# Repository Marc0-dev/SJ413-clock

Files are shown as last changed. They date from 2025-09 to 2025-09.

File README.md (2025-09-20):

# SJ413-clock
**DISCLAMER** 
The PCB dimensions are approximate, the position of the screw holes is not correct, feel free to contribute in this regard.<br />
You must have the original plastic casing to assemble the clock.<br />
Pointers are much appreciated(i'm still an amateur in electronics).<br />
This project is not complete(it may change and improve in the future).
immagine
immagine

The project is a replacement of the original suzuki sj-413 dashboard clock. All code on these repository is made using platformIO, leveraging the inexpensive wch ch32v003f4p6 MCU.<br />
List of components(lcsc part numbers):<br />
C1(100nf): C14663, <br />
C2(1uf): C28322, <br />
C3(470uf):C5162352, <br />
C4(330uf):C3032175, <br />
C5(12pf):C76948, <br />
C6(100nf):C14663, <br />
D1:C5357977, <br />
D2:C552776, <br />
J1(oled display connector), <br />
J2(wch-linke interface), <br />
J4(molex connector for rtc), <br />
J5(power connector), <br />
L1(47uh/2A): C5189938, <br />
R1(4k7):C99782, <br />
R2(4k7):C99782, <br />
U1(mcu):C5187096, <br />
U2(buck converter):C2681226, <br />
U3(real time clock):C7440, <br />
Y1:C90945, <br />
display used: C5248081, <br />
# external connection
connector
you should use only the top row of the connector: the left one is positive, the right one is negative
#Images(from previous iteration, without reverse current protection):
immagine
immagine

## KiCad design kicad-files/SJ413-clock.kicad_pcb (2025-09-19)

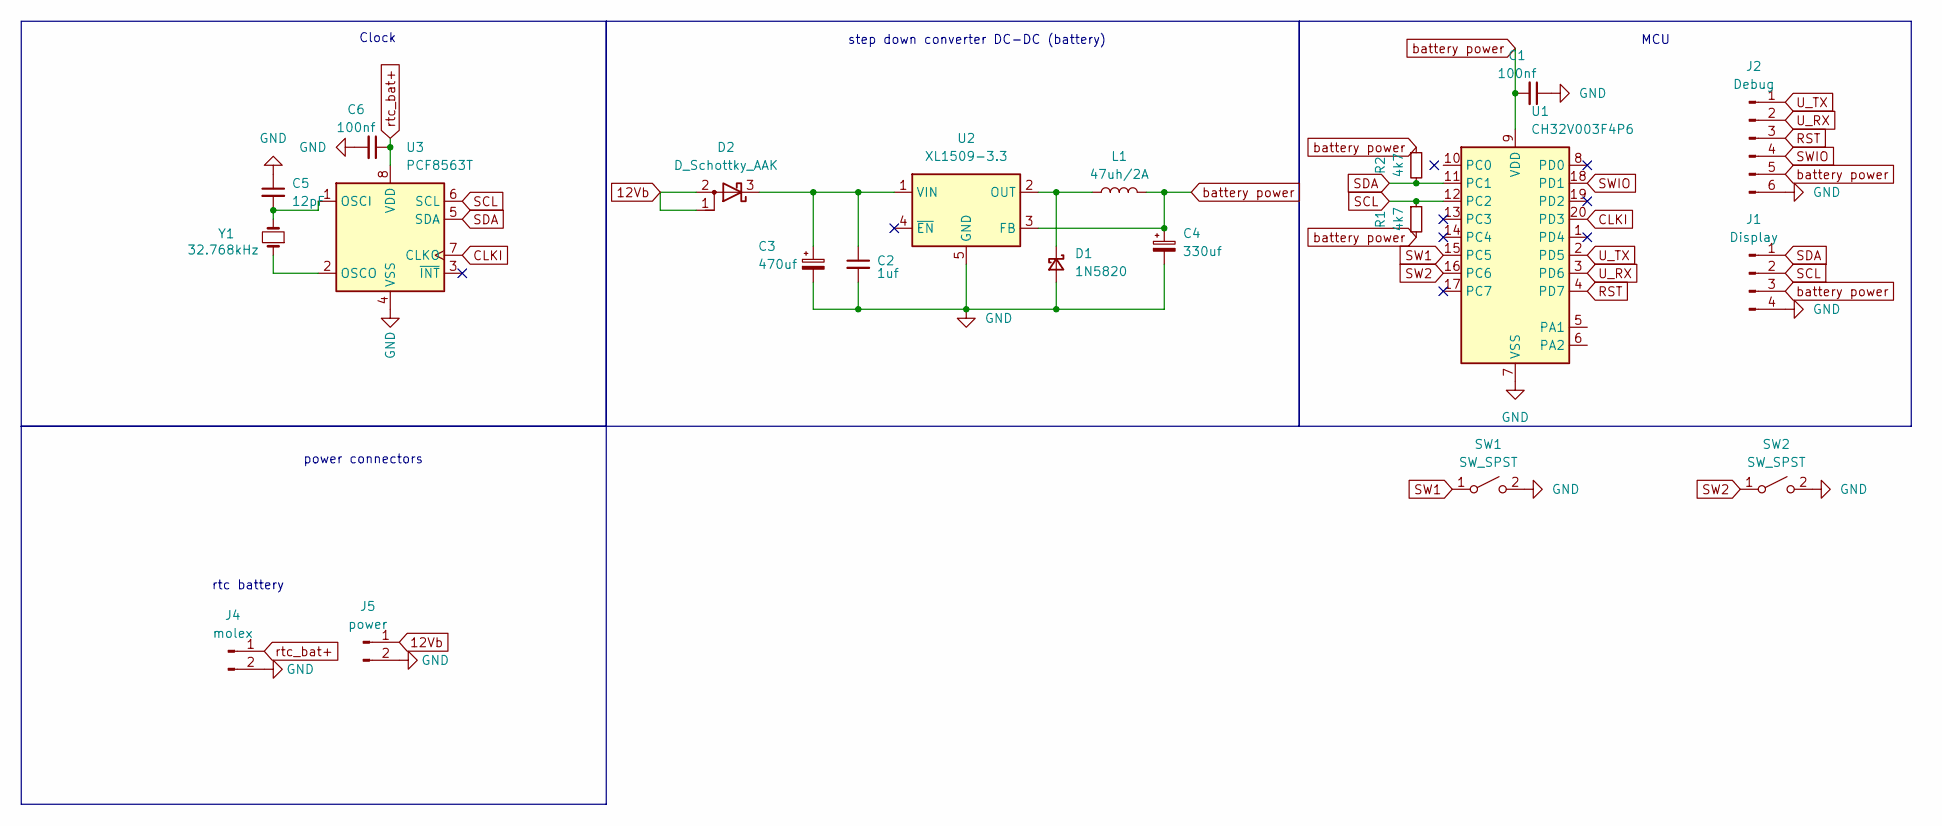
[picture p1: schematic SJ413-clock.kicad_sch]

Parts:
C1, C6: 100nf; C_0603_1608Metric; MPN CC0603KRX7R9BB104
C2: 1uf; C_1206_3216Metric
C3: 470uf; CP_Elec_10x10.5
C4: 330uf; CP_Elec_10x10.5
C5: 12pF; C_0402_1005Metric; MPN 0402CG120J500NT
D1: 1N5820; D_DO-201AD_P15.24mm_Horizontal
D2: D_Schottky_AAK; DIO_PMEG050V150EPDZ
J1: Display; PinHeader_1x04_P2.54mm_Vertical_SMD_Pin1Left
J2: Debug; PinSocket_1x06_P2.54mm_Vertical_SMD_Pin1Left
J4: molex; Molex_PicoBlade_53047-0210_1x02_P1.25mm_Vertical
J5: power; PinSocket_1x02_P2.54mm_Vertical_SMD_Pin1Left
L1: 47uh/2A; L_Sumida_CDMC6D28_7.25x6.5mm
R1, R2: 4k7; R_0603_1608Metric
SW1, SW2: SW_SPST; membrane switch
U1: CH32V003F4P6; TSSOP-20_4.4x6.5mm_P0.65mm; MPN CH32V003F4P6
U2: XL1509-3.3; SOIC-8_3.9x4.9mm_P1.27mm
U3: PCF8563T; SOIC-8_3.9x4.9mm_P1.27mm; MPN PCF8563T/5,518
Y1: 32.768kHz; Crystal_SMD_3215-2Pin_3.2x1.5mm; MPN 9H03200034

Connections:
12Vb: D2.1 (A), D2.2 (A), J5.1
CLKI: U1.20 (PD3), U3.7 (CLKO)
GND: C1.1, C2.2, C3.2, C4.2, C5.1, C6.2, D1.2 (A), J1.4, J2.6, J4.2, J5.2, SW1.2 (B), SW2.2 (B), U1.7 (VSS), U2.5 (GND), U2.6 (GND), U2.7 (GND), U2.8 (GND), U3.4 (VSS)
unnamed: D1.1 (K), L1.1, U2.2 (OUT)
unnamed: C2.1, C3.1, D2.3 (K), U2.1 (VIN)
unnamed: C5.2, U3.1 (OSCI), Y1.2
unnamed: U3.2 (OSCO), Y1.1
RST: J2.3, U1.4 (PD7)
SCL: J1.2, R1.1, U1.12 (PC2), U3.6 (SCL)
SDA: J1.1, R2.2, U1.11 (PC1), U3.5 (SDA)
SW1: SW1.1 (A), U1.15 (PC5)
SW2: SW2.1 (A), U1.16 (PC6)
SWIO: J2.4, U1.18 (PD1)
U_RX: J2.2, U1.3 (PD6)
U_TX: J2.1, U1.2 (PD5)
battery power: C1.2, C4.1, J1.3, J2.5, L1.2, R1.2, R2.1, U1.9 (VDD), U2.3 (FB)
rtc_bat+: C6.1, J4.1, U3.8 (VDD)

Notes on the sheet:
MCU
power connectors
Clock
step down converter DC-DC (battery)
rtc battery

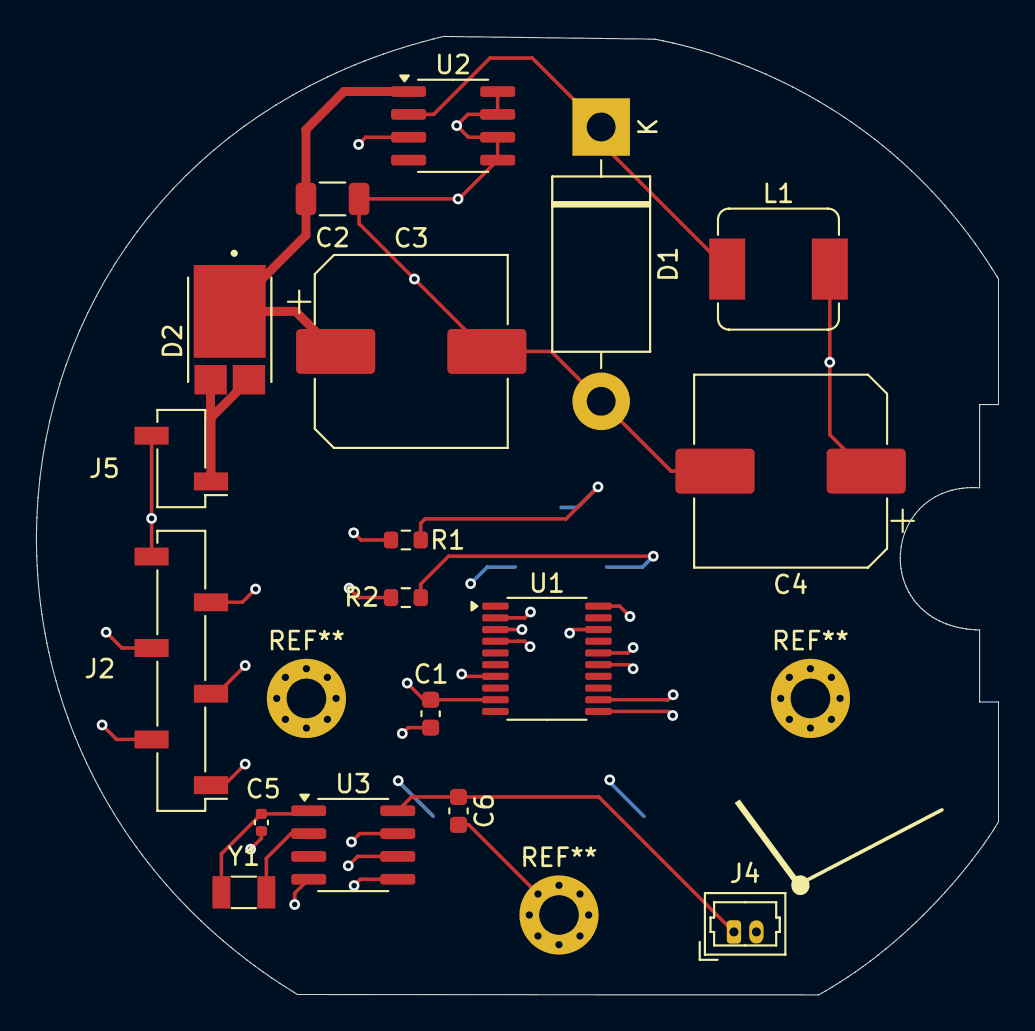
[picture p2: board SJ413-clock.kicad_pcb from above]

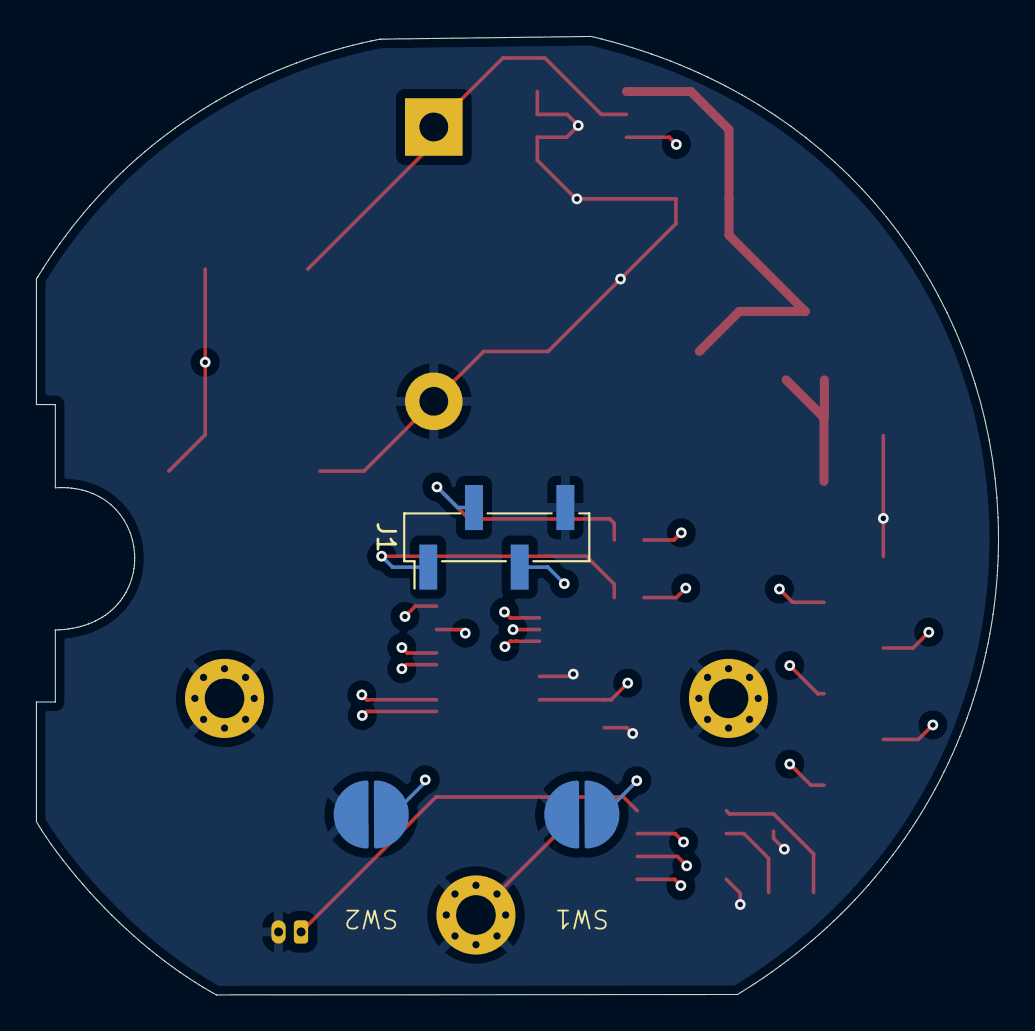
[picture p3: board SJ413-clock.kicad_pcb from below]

Board: 4 copper layers, 53.4 x 53.2 mm, 21 parts (3 on the bottom side), 17 nets.

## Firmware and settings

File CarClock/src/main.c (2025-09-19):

#include  "clock.h"
void EXTI3_INT_INIT(void){
    GPIO_InitTypeDef GPIO_InitStructure = {0};
    EXTI_InitTypeDef EXTI_InitStructure = {0};
    NVIC_InitTypeDef NVIC_InitStructure = {0};

    RCC_APB2PeriphClockCmd(RCC_APB2Periph_AFIO | RCC_APB2Periph_GPIOD, ENABLE);

    GPIO_InitStructure.GPIO_Pin = GPIO_Pin_3;
    GPIO_InitStructure.GPIO_Mode = GPIO_Mode_IPU;
    GPIO_Init(GPIOD, &GPIO_InitStructure);

    GPIO_EXTILineConfig(GPIO_PortSourceGPIOD, GPIO_PinSource3);
    EXTI_InitStructure.EXTI_Line = EXTI_Line3;
    EXTI_InitStructure.EXTI_Mode = EXTI_Mode_Interrupt;
    EXTI_InitStructure.EXTI_Trigger = EXTI_Trigger_Rising;
    EXTI_InitStructure.EXTI_LineCmd = ENABLE;
    EXTI_Init(&EXTI_InitStructure);

    NVIC_InitStructure.NVIC_IRQChannel = EXTI7_0_IRQn;
    NVIC_InitStructure.NVIC_IRQChannelPreemptionPriority = 0;
    NVIC_InitStructure.NVIC_IRQChannelSubPriority = 1;
    NVIC_InitStructure.NVIC_IRQChannelCmd = ENABLE;
    NVIC_Init(&NVIC_InitStructure);
}
int main(){
    init();
    EXTI3_INT_INIT();
    InitClock();  
}
void EXTI7_0_IRQHandler(void) __attribute__((interrupt("WCH-Interrupt-fast")));
void EXTI7_0_IRQHandler(void){
    if(EXTI_GetITStatus(EXTI_Line3)!=RESET){
        countSeconds++;
        EXTI_ClearITPendingBit(EXTI_Line3); 
    }
}

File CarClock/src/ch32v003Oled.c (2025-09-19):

#include "ch32v003Oled.h"
const uint8_t initSequence[] = {
    0XAE,
    0x00,
    0x10,
    0x00,
    0xB0,
    0x81,
    0xff,
    0xA0,
    0xA6,
    0xA8,
    0x1F,
    0xC8,
    0xD3,
    0x00,
    0xD5,
    0x80,
    0xD9,
    0x1f,
    0xDA,
    0x00,
    0xdb,
    0x40,
    0x8d,
    0x14,
    0x20,
    0x01,
    0xA4,
    0xAF
};
const uint8_t Font[CHARACTER_NUMBER][24][4] = {//to reduce
    {
        {0x00, 0x00, 0x00, 0x00},
        {0x00, 0x00, 0x00, 0x00},
        {0x00, 0x00, 0x00, 0x00},
        {0x80, 0xFF, 0xFF, 0x01},
        {0x80, 0xFF, 0xFF, 0x01},
        {0x80, 0xFF, 0xFF, 0x01},
        {0xE0, 0x00, 0x00, 0x0E},
        {0xE0, 0x00, 0x00, 0x0E},
        {0xE0, 0x00, 0x00, 0x0E},
        {0xE0, 0x00, 0x00, 0x0E},
        {0xE0, 0x00, 0x00, 0x0E},//0
        {0xE0, 0x00, 0x00, 0x0E},
        {0xE0, 0x00, 0x00, 0x0E},
        {0xE0, 0x00, 0x00, 0x0E},
        {0xE0, 0x00, 0x00, 0x0E},
        {0xE0, 0x00, 0x00, 0x0E},
        {0xE0, 0x00, 0x00, 0x0E},
        {0xE0, 0x00, 0x00, 0x0E},
        {0x80, 0xFF, 0xFF, 0x01},
        {0x80, 0xFF, 0xFF, 0x01},
        {0x80, 0xFF, 0xFF, 0x01},
        {0x00, 0x00, 0x00, 0x00},
        {0x00, 0x00, 0x00, 0x00},
        {0x00, 0x00, 0x00, 0x00}
    },
    {
        {0x00, 0x00, 0x00, 0x00},
        {0x00, 0x00, 0x00, 0x00},
        {0x00, 0x00, 0x00, 0x00},
        {0x38, 0x00, 0xE0, 0x00},
        {0x38, 0x00, 0xE0, 0x00},
        {0x38, 0x00, 0xE0, 0x00},
        {0x38, 0x00, 0xE0, 0x00},
        {0x38, 0x00, 0xE0, 0x00},
        {0x38, 0x00, 0xE0, 0x00},
        {0x38, 0x00, 0x00, 0x07},
        {0x38, 0x00, 0x00, 0x07},
        {0x38, 0x00, 0x00, 0x07},
        {0xF8, 0xFF, 0xFF, 0x07},//1
        {0xF8, 0xFF, 0xFF, 0x07},
        {0xF8, 0xFF, 0xFF, 0x07},
        {0x38, 0x00, 0x00, 0x00},
        {0x38, 0x00, 0x00, 0x00},
        {0x38, 0x00, 0x00, 0x00},
        {0x38, 0x00, 0x00, 0x00},
        {0x38, 0x00, 0x00, 0x00},
        {0x38, 0x00, 0x00, 0x00},
        {0x00, 0x00, 0x00, 0x00},
        {0x00, 0x00, 0x00, 0x00},
        {0x00, 0x00, 0x00, 0x00}
    },
    {
        {0x00, 0x00, 0x00, 0x00},
        {0x00, 0x00, 0x00, 0x00},
        {0x00, 0x00, 0x00, 0x00},
        {0b01110000, 0x00, 0b11111000, 0b00000001},
        {0b01110000, 0x00, 0b11111000, 0b00000001},
        {0b01110000, 0x00, 0b11111000, 0b00000001},
        {0b11110000, 0b00000011, 0x00, 0b00001110},
        {0b11110000, 0b00000011, 0x00, 0b00001110},
        {0b11110000, 0b00000011, 0x00, 0b00001110},
        {0b01110000, 0b00011100, 0x00, 0b00001110},
        {0b01110000, 0b00011100, 0x00, 0b00001110},//2
        {0b01110000, 0b00011100, 0x00, 0b00001110},
        {0b01110000, 0b11100000, 0x00, 0b00001110},
        {0b01110000, 0b11100000, 0x00, 0b00001110},
        {0b01110000, 0b11100000, 0x00, 0b00001110},
        {0b01110000, 0b11100000, 0x00, 0b00001110},
        {0b01110000, 0b11100000, 0x00, 0b00001110},
        {0b01110000, 0b11100000, 0x00, 0b00001110},
        {0b11110000, 0b00000011, 0xFF, 0b00000001},
        {0b11110000, 0b00000011, 0xFF, 0b00000001},
        {0b11110000, 0b00000011, 0xFF, 0b00000001},
        {0x00, 0x00, 0x00, 0x00},
        {0x00, 0x00, 0x00, 0x00},
        {0x00, 0x00, 0x00, 0x00}
    },
    {
        {0x00, 0x00, 0x00, 0x00},
        {0x00, 0x00, 0x00, 0x00},
        {0x00, 0x00, 0x00, 0x00},
        {0b10000000, 0b00000011, 0b11000000, 0b00000001},
        {0b10000000, 0b00000011, 0b11000000, 0b00000001},
        {0b10000000, 0b00000011, 0b11000000, 0b00000001},
        {0b01110000, 0x00, 0x00, 0b00001110},
        {0b01110000, 0x00, 0x00, 0b00001110},
        {0b01110000, 0x00, 0x00, 0b00001110},
        {0b01110000, 0x00, 0x00, 0b00001110},
        {0b01110000, 0x00, 0x00, 0b00001110},//3
        {0b01110000, 0x00, 0x00, 0b00001110},
        {0b01110000, 0x00, 0b00111000, 0b00001110},
        {0b01110000, 0x00, 0b00111000, 0b00001110},
        {0b01110000, 0x00, 0b00111000, 0b00001110},
        {0b01110000, 0x00, 0b00111000, 0b00001110},
        {0b01110000, 0x00, 0b00111000, 0b00001110},
        {0b01110000, 0x00, 0b00111000, 0b00001110},
        {0b10000000, 0xFF, 0b11000111, 0b00000001},
        {0b10000000, 0xFF, 0b11000111, 0b00000001},
        {0b10000000, 0xFF, 0b11000111, 0b00000001},
        {0x00, 0x00, 0x00, 0x00},
        {0x00, 0x00, 0x00, 0x00},
        {0x00, 0x00, 0x00, 0x00}
    },
    {
        {0x00, 0x00, 0x00, 0x00},
        {0x00, 0x00, 0x00, 0x00},
        {0x00, 0x00, 0x00, 0x00},
        {0x00, 0x00, 0b00000111, 0x00},
        {0x00, 0x00, 0b00000111, 0x00},
        {0x00, 0x00, 0b00000111, 0x00},
        {0x00, 0b11100000, 0b11111000, 0b00001111},
        {0x00, 0b11100000, 0b11111000, 0b00001111},
        {0x00, 0b11100000, 0b11111000, 0b00001111},
        {0x00, 0b11100000, 0x00, 0x00},
        {0x00, 0b11100000, 0x00, 0x00},
        {0x00, 0b11100000, 0x00, 0x00},
        {0x00, 0b11100000, 0x00, 0x00},//4
        {0x00, 0b11100000, 0x00, 0x00},
        {0x00, 0b11100000, 0x00, 0x00},
        {0x00, 0b11100000, 0x00, 0x00},
        {0x00, 0b11100000, 0x00, 0x00},
        {0x00, 0b11100000, 0x00, 0x00},
        {0b11110000, 0xFF, 0xFF, 0b00001111},
        {0b11110000, 0xFF, 0xFF, 0b00001111},
        {0b11110000, 0xFF, 0xFF, 0b00001111},
        {0x00, 0x00, 0x00, 0x00},
        {0x00, 0x00, 0x00, 0x00},
        {0x00, 0x00, 0x00, 0x00}
    },
    {
        {0x00, 0x00, 0x00, 0x00},
        {0x00, 0x00, 0x00, 0x00},
        {0x00, 0x00, 0x00, 0x00},
        {0b10000000, 0b00011111, 0b11111000, 0b00001111},
        {0b10000000, 0b00011111, 0b11111000, 0b00001111},
        {0b10000000, 0b00011111, 0b11111000, 0b00001111},
        {0b01110000, 0x00, 0b00111000, 0b00001110},
        {0b01110000, 0x00, 0b00111000, 0b00001110},
        {0b01110000, 0x00, 0b00111000, 0b00001110},
        {0b01110000, 0x00, 0b00111000, 0b00001110},
        {0b01110000, 0x00, 0b00111000, 0b00001110},
        {0b01110000, 0x00, 0b00111000, 0b00001110},
        {0b01110000, 0x00, 0b00111000, 0b00001110},//5
        {0b01110000, 0x00, 0b00111000, 0b00001110},
        {0b01110000, 0x00, 0b00111000, 0b00001110},
        {0b01110000, 0x00, 0b00111000, 0b00001110},
        {0b01110000, 0x00, 0b00111000, 0b00001110},
        {0b01110000, 0x00, 0b00111000, 0b00001110},
        {0b10000000, 0xFF, 0b00000111, 0b00001110},
        {0b10000000, 0xFF, 0b00000111, 0b00001110},
        {0b10000000, 0xFF, 0b00000111, 0b00001110},
        {0x00, 0x00, 0x00, 0x00},
        {0x00, 0x00, 0x00, 0x00},
        {0x00, 0x00, 0x00, 0x00}
    },
    {
        {0x00, 0x00, 0x00, 0x00},
        {0x00, 0x00, 0x00, 0x00},
        {0x00, 0x00, 0x00, 0x00},
        {0b10000000, 0xFF, 0b00111111, 0x00},
        {0b10000000, 0xFF, 0b00111111, 0x00},
        {0b10000000, 0xFF, 0b00111111, 0x00},
        {0b01110000, 0b11100000, 0b11000000, 0b00000001},
        {0b01110000, 0b11100000, 0b11000000, 0b00000001},
        {0b01110000, 0b11100000, 0b11000000, 0b00000001},
        {0b01110000, 0b11100000, 0x00, 0b00001110},
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
